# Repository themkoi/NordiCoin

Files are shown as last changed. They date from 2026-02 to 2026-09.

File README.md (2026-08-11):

<h1 align="center">
NordiCoin
</h1>

<p align="center">
Open source BLE tracker with up to 6 years of battery life on a single coin cell.
</p>

<p align="center">

</p>

<p align="center">
  
</p>

- It does not rely on a corporation BLE network to find it. Just you and your devices who track it. Dedicated android app and [watchy](https://github.com/Szybet/InkWatchy) support. The app alerts you once you are out of range
- Design focuses on easy self assembly by individuals
  - Wroom package used to avoid BGA soldering
  - Place for a second MCU in a different package, if the main one is not available. It also exposes all the pins for more features
- Buzzer, to find it easier and a button to stop buzzing
- Wanna use it as a remote for home automation? Sure, that's possible
- Built using the nrf52805
- Firmware written in rust
- Further potential to improve battery life

### Licence
Open Community License v1.1 + General Attribution v1

### Contact
Github issues, [Yatchy discord server](https://github.com/Szybet/Yatchy), [Quill OS matrix space](https://quill-os.org)

### Power consumption
It's a spectrum, the absolute best I got was 3.7uA



But this, at least with the current method is hard to connect to because it's 5s of advertisement delay, not 4s. With 4, it's around 4.5uA. Explore the `battery_life.ods` file to confirm

If someone really wanted to, it would be possible to sync time, advertise only on full minute, make the app do the same and this way it would advertise 15 times less. 10 years of battery life easily achievable. But connecting to it, at least with regular android phones would take long/impossible. That's why I decided the current setup is good enough

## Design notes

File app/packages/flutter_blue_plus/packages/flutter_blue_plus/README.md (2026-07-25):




<br>
<p align="center">
FlutterBlue
</p>
<br><br>

## Sponsor

<p align="left">
FlutterBlue
</p>

FlutterBluePlus is sponsored by [Jamcorder](https://www.jamcorder.com/). 

## License

FlutterBluePlus is licensed under the **[FlutterBluePlus License](./LICENSE.md)**.

* **Nonprofit use**: Free for personal use, nonprofits, and educational institutions. No license required.  
* **Commercial use**: For for-profit use, by for-profit organizations or individuals, a [Commercial License](https://jamcorder.myshopify.com/products/flutterblueplus-commercial-license) is required. This license grants *lifetime use*, covers all FlutterBluePlus packages, and includes *lifetime updates*.

---

**Note: this plugin is continuous work from [FlutterBlue](https://github.com/pauldemarco/flutter_blue).**

Migrating from [FlutterBlue](https://github.com/pauldemarco/flutter_blue)? See [Migration Guide](./MIGRATION.md)

## Contents

- [Introduction](#introduction)
- [Usage](#usage)
- [Getting Started](#getting-started)
- [Using Ble in App Background](#using-ble-in-app-background)
- [API Reference](#api-reference)
- [Debugging](#debugging)
- [Mocking](#mocking)
- [Common Problems](#common-problems)

## Introduction

FlutterBluePlus is a Bluetooth Low Energy plugin for [Flutter](https://flutter.dev). 

It supports BLE Central Role only (most common). 

If you need BLE Peripheral Role, you should check out [FlutterBlePeripheral](https://pub.dev/packages/flutter_ble_peripheral), or [bluetooth_low_energy](https://pub.dev/packages/bluetooth_low_energy).

## Tutorial

If you are new to Bluetooth, you should start by reading BLE tutorials.
* [Novel Bits BLE Tutorial](https://novelbits.io/bluetooth-low-energy-ble-complete-guide/)
* [All About Circuits BLE Tutorial](https://www.allaboutcircuits.com/technical-articles/exploring-the-basics-of-bluetooth-low-energy-a-beginners-guide-to-ble/)
* [Embetronicx BLE Tutorial](https://embetronicx.com/tutorials/tech_devices/bluetooth-low-energy-ble-introduction-part-1/)

## ❗ Bluetooth Classic is not supported ❗

 i.e. **Arduino HC-05 & HC-06,** speakers, headphones, mice, keyboards, gamepads, and more are **not** supported. These all use Bluetooth Classic.

 Also, iBeacons are **_not_** supported on iOS. Apple requires you to use CoreLocation.

## Cross-Platform Bluetooth Low Energy

FlutterBluePlus supports nearly every feature on all supported platforms: iOS, macOS, Android, Linux, Web.

## No Dependencies

FlutterBluePlus has zero dependencies besides Flutter, Android, iOS, and macOS themselves.

This makes FlutterBluePlus very stable, and easy to maintain.

## Windows Support

Use [flutter_blue_plus_winrt](https://pub.dev/packages/flutter_blue_plus_winrt) if you need Windows support.

It is maintained by [@chan150](https://github.com/chan150).

## ⭐ Stars ⭐

Please star this repo & on [pub.dev](https://pub.dev/packages/flutter_blue_plus). We all benefit from having a larger community.

## Discord 💬

 There is a community Discord server. ([Link](https://discord.gg/Yk5Efra))

## Example

FlutterBluePlus has a beautiful example app, useful to debug issues.

```
cd ./example
flutter run
```

<p align="center">
FlutterBlue
</p>

## Usage

### 🔥 Error Handling 🔥

Flutter Blue Plus takes error handling seriously. 

Every error returned by the native platform is checked and thrown as an exception where appropriate.

**Streams:** Streams returned by FlutterBluePlus never emit any errors and never close. There's no need to handle `onError` or `onDone` for  `stream.listen(...)`. The one exception is `FlutterBluePlus.scanResults`, which you should handle `onError`.

---

### Set Log Level

```dart
// if your terminal doesn't support color you'll see annoying logs like `\x1B[1;35m`
FlutterBluePlus.setLogLevel(LogLevel.verbose, color:false);

// optional
FlutterBluePlus.logs.listen((String s){
    // send logs anywhere you want
});
```

Setting `LogLevel.verbose` shows *all* data in and out.

⚫ = function name

🟣 = args to platform

🟡 = data from platform



### Bluetooth On & Off

**Note:** On iOS, a "*This app would like to use Bluetooth*" system dialogue appears on first call to any FlutterBluePlus method. 
 
```dart
// first, check if bluetooth is supported by your hardware
// Note: The platform is initialized on the first call to any FlutterBluePlus method.
if (await FlutterBluePlus.isSupported == false) {
    print("Bluetooth not supported by this device");
    return;
}

// handle bluetooth on & off
// note: for iOS the initial state is typically BluetoothAdapterState.unknown
// note: if you have permissions issues you will get stuck at BluetoothAdapterState.unauthorized
var subscription = FlutterBluePlus.adapterState.listen((BluetoothAdapterState state) {
    print(state);
    if (state == BluetoothAdapterState.on) {
        // usually start scanning, connecting, etc
    } else {
        // show an error to the user, etc
    }
});

// turn on bluetooth ourself if we can
// for iOS, the user controls bluetooth enable/disable
if (!kIsWeb && Platform.isAndroid) {
    await FlutterBluePlus.turnOn();
}

// cancel to prevent duplicate listeners
subscription.cancel();
```

### Scan for devices

If your device is not found, see [Common Problems](#common-problems).

**Note:** It is recommended to set scan filters to reduce main thread & platform channel usage.

```dart
// listen to scan results
// Note: `onScanResults` clears the results between scans. You should use
//  `scanResults` if you want the current scan results *or* the results from the previous scan.
var subscription = FlutterBluePlus.onScanResults.listen((results) {
        if (results.isNotEmpty) {
            ScanResult r = results.last; // the most recently found device
            print('${r.device.remoteId}: "${r.advertisementData.advName}" found!');
        }
    },
    onError: (e) => print(e),
);

// cleanup: cancel subscription when scanning stops
FlutterBluePlus.cancelWhenScanComplete(subscription);

// Wait for Bluetooth enabled & permission granted
// In your real app you should use `FlutterBluePlus.adapterState.listen` to handle all states
await FlutterBluePlus.adapterState.where((val) => val == BluetoothAdapterState.on).first;

// Start scanning w/ timeout
// Optional: use `stopScan()` as an alternative to timeout
await FlutterBluePlus.startScan(
  withServices:[Guid("180D")], // match any of the specified services
  withNames:["Bluno"], // *or* any of the specified names
  timeout: Duration(seconds:15));

// wait for scanning to stop
await FlutterBluePlus.isScanning.where((val) => val == false).first;
```

### Connect to a device

```dart
// listen for disconnection
var subscription = device.connectionState.listen((BluetoothConnectionState state) async {
    if (state == BluetoothConnectionState.disconnected) {
        // 1. typically, start a periodic timer that tries to 
        //    reconnect, or just call connect() again right now
        // 2. you must always re-discover services after disconnection!
        print("${device.disconnectReason?.code} ${device.disconnectReason?.description}");
    }
});

// cleanup: cancel subscription when disconnected
//   - [delayed] This option is only meant for `connectionState` subscriptions.  
//     When `true`, we cancel after a small delay. This ensures the `connectionState` 
//     listener receives the `disconnected` event.
//   - [next] if true, the the stream will be canceled only on the *next* disconnection,
//     not the current disconnection. This is useful if you setup your subscriptions
//     before you connect.
device.cancelWhenDisconnected(subscription, delayed:true, next:true);

// Connect to the device
await device.connect();

// Disconnect from device
await device.disconnect();

// cancel to prevent duplicate listeners
subscription.cancel();
```

### Auto Connect

Connects whenever your device is found.

```dart
// enable auto connect
//  - note: autoConnect is incompatible with mtu argument, so you must call requestMtu yourself
await device.connect(autoConnect:true, mtu:null)

// wait until connection
//  - when using autoConnect, connect() always returns immediately, so we must
//    explicity listen to `device.connectionState` to know when connection occurs 
await device.connectionState.where((val) => val == BluetoothConnectionState.connected).first;

// disable auto connect
await device.disconnect()
```

### Save Device

To save a device between app restarts, just write the `remoteId` to a file.

Now you can connect without needing to scan again, like so:

```dart
final String remoteId = await File('/remoteId.txt').readAsString();
var device = BluetoothDevice.fromId(remoteId);
// AutoConnect is convenient because it does not "time out"
// even if the device is not available / turned off.
await device.connect(autoConnect: true);

```

### MTU

On Android, we request an mtu of 512 by default during connection (see: `connect` function arguments).

On iOS & macOS, the mtu is negotiated automatically, typically 135 to 255.

```dart
final subscription = device.mtu.listen((int mtu) {
    // iOS: initial value is always 23, but iOS will quickly negotiate a higher value
    print("mtu $mtu");
});

// cleanup: cancel subscription when disconnected
device.cancelWhenDisconnected(subscription);

// You can also manually change the mtu yourself.
if (!kIsWeb && Platform.isAndroid) {
    await device.requestMtu(512);
}
```

### Discover services

```dart
// Note: You must call discoverServices after every re-connection!
List<BluetoothService> services = await device.discoverServices();
services.forEach((service) {
    // do something with service
});
```

### Read Characteristics

```dart
// Reads all characteristics
var characteristics = service.characteristics;
for(BluetoothCharacteristic c in characteristics) {
    if (c.properties.read) {
        List<int> value = await c.read();
        print(value);
    }
}
```

### Write Characteristic

```dart
// Writes to a characteristic
await c.write([0x12, 0x34]);
```

**allowLongWrite**: To write large characteristics (up to 512 bytes) regardless of mtu, use `allowLongWrite`:

```dart
/// allowLongWrite should be used with caution. 
///   1. it can only be used *with* response to avoid data loss
///   2. the peripheral device must support the 'long write' ble protocol.
///   3. Interrupted transfers can leave the characteristic in a partially written state
///   4. If the mtu is small, it is very very slow.
await c.write(data, allowLongWrite:true);
```

**splitWrite**: To write lots of data (unlimited), you can define the `splitWrite` function. 

```dart
import 'dart:math';
// split write should be used with caution.
//    1. due to splitting, `characteristic.read()` will return partial data.
//    2. it can only be used *with* response to avoid data loss
//    3. The characteristic must be designed to support split data
extension splitWrite on BluetoothCharacteristic {
  Future<void> splitWrite(List<int> value, {int timeout = 15}) async {
    int chunk = min(device.mtuNow - 3, 512); // 3 bytes BLE overhead, 512 bytes max
    for (int i = 0; i < value.length; i += chunk) {
      List<int> subvalue = value.sublist(i, min(i + chunk, value.length));
      await write(subvalue, withoutResponse:false, timeout: timeout);
    }
  }
}
```

### Subscribe to a characteristic

If `onValueReceived` is never called, see [Common Problems](#common-problems) in the README.

```dart
final subscription = characteristic.onValueReceived.listen((value) {
    // onValueReceived is updated:
    //   - anytime read() is called
    //   - anytime a notification arrives (if subscribed)
});

// cleanup: cancel subscription when disconnected
device.cancelWhenDisconnected(subscription);

// subscribe
// Note: If a characteristic supports both **notifications** and **indications**,
// it will default to **notifications**. This matches how CoreBluetooth works on iOS.
await characteristic.setNotifyValue(true);
```

### Last Value Stream

`lastValueStream` is an alternative to `onValueReceived`. It emits a value any time the characteristic changes, **including writes.**

It is very convenient for simple characteristics that support both WRITE and READ (and/or NOTIFY). **e.g.** a "light switch toggle" characteristic. 

```dart
final subscription = characteristic.lastValueStream.listen((value) {
    // lastValueStream` is updated:
    //   - anytime read() is called
    //   - anytime write() is called
    //   - anytime a notification arrives (if subscribed)
    //   - also when first listened to, it re-emits the last value for convenience.
});

// cleanup: cancel subscription when disconnected
device.cancelWhenDisconnected(subscription);

// enable notifications
await characteristic.setNotifyValue(true);
```

### Read and write descriptors

```dart
// Reads all descriptors
var descriptors = characteristic.descriptors;
for(BluetoothDescriptor d in descriptors) {
    List<int> value = await d.read();
    print(value);
}

// Writes to a descriptor
await d.write([0x12, 0x34])
```

### Services Changed Characteristic

FlutterBluePlus automatically listens to the Services Changed Characteristic (0x2A05)

In FlutterBluePlus, we call it `onServicesReset` because you must re-discover services.

```dart
// - uses the GAP Services Changed characteristic (0x2A05)
// - you must call discoverServices() again
device.onServicesReset.listen(() async {
    print("Services Reset");
    await device.discoverServices();
});
```

### Get Connected Devices

Get devices currently connected to your app.

```dart
List<BluetoothDevice> devs = FlutterBluePlus.connectedDevices;
for (var d in devs) {
    print(d);
}
```

### Get System Devices

Get devices connected to the system by *any* app.

**Note:** before you can communicate, you must connect *your app* to these devices 

```dart
// `withServices` required on iOS, ignored on android
List<Guid> withServices = [Guid("180F")]; // e.g. Battery Service
List<BluetoothDevice> devs = await FlutterBluePlus.systemDevices(withServices);
for (var d in devs) {
    await d.connect(); // Must connect *our* app to the device
    await d.discoverServices();
}
```

### Create Bond (Android Only)

**Note:** calling this is usually not necessary!! The platform will do it automatically. 

However, you can force the popup to show sooner.

```dart
final bsSubscription = device.bondState.listen((value) {
    print("$value prev:{$device.prevBondState}");
});

// cleanup: cancel subscription when disconnected
device.cancelWhenDisconnected(bsSubscription);

// Force the bonding popup to show now (Android Only) 
await device.createBond();

// remove bond
await device.removeBond();
```

### Events API

Access streams from all devices simultaneously.

There are streams for:
* events.onConnectionStateChanged
* events.onMtuChanged
* events.onReadRssi
* events.onServicesReset
* events.onDiscoveredServices
* events.onCharacteristicReceived
* events.onCharacteristicWritten
* events.onDescriptorRead
* events.onDescriptorWritten
* events.onNameChanged (iOS Only)
* events.onBondStateChanged (Android Only)

```dart
// listen to *any device* connection state changes 
FlutterBluePlus.events.onConnectionStateChanged.listen((event)) {
    print('${event.device} ${event.connectionState}');
}
```

### Multi Device Performance

We recommend setting per-device queueing. 

```dart
// note: call this function before starting any other FBP work
FlutterBluePlus.setOperationQueueMode(OperationQueueMode.perDevice);
```

This allows BLE operations on different devices to run at the same time, increasing multi-device performance.

## Mocking

To mock `FlutterBluePlus` for development, refer to the [Mocking Guide](MOCKING.md).

## Getting Started

### Add the `flutter_blue_plus` plugin

We recommend that you pin to a specific version of the `flutter_blue_plus` plugin for maximum stability and to avoid small breaking changes.

```shell
flutter pub add flutter_blue_plus:x.y.z
```

`flutter_blue_plus` is a [federated plugin](https://docs.flutter.dev/packages-and-plugins/developing-packages#federated-plugins) with endorsed platform implementations therefore you only need to add the "app-facing package" to your `pubspec.yaml` file.

### Change the minSdkVersion for Android

flutter_blue_plus is compatible only from version 21 of Android SDK so you should change this in **android/app/build.gradle**:

```dart
android {
  defaultConfig {
     minSdkVersion: 21
```

### Add permissions for Android (No Location)

In the **android/app/src/main/AndroidManifest.xml** add:

```xml
<!-- Tell Google Play Store that your app uses Bluetooth LE
     Set android:required="true" if bluetooth is necessary -->
<uses-feature android:name="android.hardware.bluetooth_le" android:required="false" />

<!-- New Bluetooth permissions in Android 12
https://developer.android.com/about/versions/12/features/bluetooth-permissions -->
<uses-permission android:name="android.permission.BLUETOOTH_SCAN" android:usesPermissionFlags="neverForLocation" />
<uses-permission android:name="android.permission.BLUETOOTH_CONNECT" />

<!-- legacy for Android 11 or lower -->
<uses-permission android:name="android.permission.BLUETOOTH" android:maxSdkVersion="30" />
<uses-permission android:name="android.permission.BLUETOOTH_ADMIN" android:maxSdkVersion="30" />
<uses-permission android:name="android.permission.ACCESS_FINE_LOCATION" android:maxSdkVersion="30"/>

<!-- legacy for Android 9 or lower -->
<uses-permission android:name="android.permission.ACCESS_COARSE_LOCATION" android:maxSdkVersion="28" />
```

### Add permissions for Android (With Fine Location)

If you want to use Bluetooth to determine location, or support iBeacons.

In the **android/app/src/main/AndroidManifest.xml** add:

```xml
<!-- Tell Google Play Store that your app uses Bluetooth LE
     Set android:required="true" if bluetooth is necessary -->
<uses-feature android:name="android.hardware.bluetooth_le" android:required="false" />

<!-- New Bluetooth permissions in Android 12
https://developer.android.com/about/versions/12/features/bluetooth-permissions -->
<uses-permission android:name="android.permission.BLUETOOTH_SCAN"/>
<uses-permission android:name="android.permission.BLUETOOTH_CONNECT" />
<uses-permission android:name="android.permission.ACCESS_FINE_LOCATION" />

<!-- legacy for Android 11 or lower -->
<uses-permission android:name="android.permission.BLUETOOTH" android:maxSdkVersion="30" />
<uses-permission android:name="android.permission.BLUETOOTH_ADMIN" android:maxSdkVersion="30" />

<!-- legacy for Android 9 or lower -->
<uses-permission android:name="android.permission.ACCESS_COARSE_LOCATION" android:maxSdkVersion="28" />
```

And set **androidUsesFineLocation** when scanning:
```dart
// Start scanning
flutterBlue.startScan(timeout: Duration(seconds: 4), androidUsesFineLocation: true);
```

### Android Proguard

Add the following line in your `project/android/app/proguard-rules.pro` file:

```
-keep class com.lib.flutter_blue_plus.* { *; }
```

to avoid seeing the following kind errors in your `release` builds:

```
PlatformException(startScan, Field androidScanMode_ for m0.e0 not found. Known fields are
 [private int m0.e0.q, private b3.b0$i m0.e0.r, private boolean m0.e0.s, private static final m0.e0 m0.e0.t,
 private static volatile b3.a1 m0.e0.u], java.lang.RuntimeException: Field androidScanMode_ for m0.e0 not found
```

### Add permissions for iOS

In the **ios/Runner/Info.plist** let’s add:

```dart
<dict>
...
    <key>NSBluetoothAlwaysUsageDescription</key>
    <string>This app needs Bluetooth to function</string>
...
</dict>
```

For location permissions on iOS see more at: [https://developer.apple.com/documentation/corelocation/requesting_authorization_for_location_services](https://developer.apple.com/documentation/corelocation/requesting_authorization_for_location_services)

### Add permissions for macOS 

Make sure you have granted access to the Bluetooth hardware:

`Xcode -> Runners -> Targets -> Runner-> Signing & Capabilities -> App Sandbox -> Hardware -> Enable Bluetooth`



## Using Ble in App Background

**This is an advanced use case**. FlutterBluePlus does not support everything. You may have to fork it. PRs are welcome.

### iOS

Documentation: https://developer.apple.com/library/archive/documentation/NetworkingInternetWeb/Conceptual/CoreBluetooth_concepts/CoreBluetoothBackgroundProcessingForIOSApps/Perform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

Add the following to your `Info.plist`

```
<key>UIBackgroundModes</key>
<array>
    <string>bluetooth-central</string>
</array>
```

When this key-value pair is included in the app’s Info.plist file, the system wakes up your app to process ble `read`, `write`, and `subscription` events.

To wake up your app even after it is killed by the OS, set the `restoreState` option to true **before** starting any FBP work**:

```
FlutterBluePlus.setOptions(restoreState: true);
```

**Note**: Upon being woken up, an app has around 10 seconds to complete a task. Apps that spend too much time executing in the background can be throttled back by the system or killed.

### Android

You can try using https://pub.dev/packages/flutter_foreground_task or possibly https://pub.dev/packages/workmanager

## API Reference

Note: When functionality is unsupported on a platform, sensible defaults are returned instead of an error.

* 🌀 = Stream
* ⚡ = Synchronous
* 🔥 = Can fail

| | Android | iOS/macOS | Linux | Web | Description |
|---|---|---|---|-----|---|
| setLogLevel | ✔️ | ✔️ | ✔️ | ❌ | Configure plugin log level |
| setOptions | ✔️ | ✔️ | ❌ | ❌ | Set configurable bluetooth options |
| setOperationQueueMode ⚡| ✔️ | ✔️ | ✔️ | ✔️  | Configure whether BLE operations queue globally or per-device |
| isSupported | ✔️ | ✔️ | ✔️ | ✔️  | Checks whether the device supports Bluetooth |
| turnOn 🔥| ✔️ | ❌ | ✔️ | ❌ | Turns on the bluetooth adapter |
| turnOff 🔥| ✔️ | ❌ | ✔️ | ❌ | Turns off the bluetooth adapter |
| adapterStateNow ⚡| ✔️ | ✔️ | ✔️ | ❌ | Current state of the bluetooth adapter |
| adapterState 🌀| ✔️ | ✔️ | ✔️ | ❌ | Stream of on & off states of the bluetooth adapter |
| startScan 🔥| ✔️ | ✔️ | ✔️ | ✔️  | Starts a scan for Ble devices |
| stopScan 🔥| ✔️ | ✔️ | ✔️ | ❌ | Stop an existing scan for Ble devices |
| onScanResults 🌀🔥| ✔️ | ✔️ | ✔️ | ✔️  | Stream of live scan results |
| scanResults 🌀🔥| ✔️ | ✔️ | ✔️ | ✔️  | Stream of live scan results or previous results |
| lastScanResults ⚡| ✔️ | ✔️ | ✔️ | ✔️  | The most recent scan results |
| isScanning 🌀| ✔️ | ✔️ | ✔️ | ✔️  | Stream of current scanning state |
| isScanningNow ⚡| ✔️ | ✔️ | ✔️ | ✔️  | Is a scan currently running? |
| connectedDevices ⚡| ✔️ | ✔️ | ✔️ | ✔️  | List of devices connected to *your app* |
| systemDevices 🔥| ✔️ | ✔️ | ✔️ | ❌ | List of devices connected to the system, even by other apps |
| getPhySupport | ✔️ | ❌ | ❌ | ❌ | Get supported bluetooth phy codings |

### FlutterBluePlus Events API

| | Android | iOS/macOS | Linux | Web | Description |
|---|---|---|---|-----|---|
| onConnectionStateChanged 🌀| ✔️ | ✔️ | ✔️ | ✔️  | Stream of connection changes of *all devices* |
| onMtuChanged 🌀| ✔️ | ✔️ | ❌ | ❌ | Stream of mtu changes of *all devices* |
| onReadRssi 🌀| ✔️ | ✔️ | ✔️ | ❌ | Stream of rssi reads of *all devices* |
| onServicesReset 🌀| ✔️ | ✔️ | ✔️ | ❌ | Stream of services resets of *all devices* |
| onDiscoveredServices 🌀| ✔️ | ✔️ | ✔️ | ✔️  | Stream of services discovered of *all devices* |
| onCharacteristicReceived 🌀| ✔️ | ✔️ | ✔️ | ✔️  | Stream of characteristic value reads of *all devices*  |
| onCharacteristicWritten  🌀| ✔️ | ✔️ | ✔️ | ✔️  | Stream of characteristic value writes of *all devices* |
| onDescriptorRead 🌀| ✔️ | ✔️ | ✔️ | ✔️  | Stream of descriptor value reads of *all devices* |
| onDescriptorWritten 🌀| ✔️ | ✔️ | ✔️ | ✔️  | Stream of descriptor value writes of *all devices* |
| onBondStateChanged 🌀| ✔️ | ❌ | ✔️ | ❌ | Stream of bond state changes of *all devices* |
| onNameChanged 🌀| ❌ | ✔️ | ✔️ | ❌ | Stream of name changes of *all devices* |

### BluetoothDevice API

| | Android | iOS/macOS | Linux | Web | Description |
|---|---|---|---|-----|---|
| platformName ⚡| ✔️ | ✔️ | ✔️ | ✔️  | The platform preferred name of the device |
| advName ⚡| ✔️ | ✔️ | ❌ | ❌ | The advertised name of the device found during scanning |
| connect 🔥| ✔️ | ✔️ | ✔️ | ✔️  | Establishes a connection to the device |
| disconnect 🔥| ✔️ | ✔️ | ✔️ | ✔️  | Cancels an active or pending connection to the device |
| isConnected ⚡| ✔️ | ✔️ | ✔️ | ✔️  | Is this device currently connected to *your app*? |
| isDisconnected ⚡| ✔️ | ✔️ | ✔️ | ✔️  | Is this device currently disconnected from *your app*? |
| connectionState 🌀| ✔️ | ✔️ | ✔️ | ✔️  | Stream of connection changes for the Bluetooth Device |
| discoverServices 🔥| ✔️ | ✔️ | ✔️ | ✔️  | Discover services |
| servicesList ⚡| ✔️ | ✔️ | ✔️ | ✔️  | The current list of available services |
| onServicesReset 🌀| ✔️ | ✔️ | ✔️ | ❌ | The services changed & must be rediscovered |
| mtu 🌀| ✔️ | ✔️ | ❌ | ❌ | Stream of current mtu value + changes |
| mtuNow ⚡| ✔️ | ✔️ | ❌ | ❌ | The current mtu value |
| readRssi 🔥| ✔️ | ✔️ | ✔️ | ❌ | Read RSSI from a connected device |
| requestMtu 🔥| ✔️ | ❌ | ❌ | ❌ | Request to change the MTU for the device |
| requestConnectionPriority 🔥| ✔️ | ❌ | ❌ | ❌ | Request to update a high priority, low latency connection  |
| bondState 🌀| ✔️ | ❌ | ✔️ | ❌ | Stream of device bond state. Can be useful on Android |
| createBond 🔥| ✔️ | ❌ | ✔️ | ❌ | Force a system pairing dialogue to show, if needed |
| removeBond | ✔️ | ❌ | ✔️ | ❌ | Remove Bluetooth Bond of device |
| setPreferredPhy | ✔️ | ❌ | ❌ | ❌ | Set preferred RX and TX phy for connection and phy options |
| clearGattCache | ✔️ | ❌ | ❌ | ❌ | Clear android cache of service discovery results |

### BluetoothCharacteristic API

| | Android | iOS/macOS | Linux | Web | Description |
|---|---|---|---|-----|---|
| uuid ⚡| ✔️ | ✔️ | ✔️ | ✔️  | The uuid of characteristic |
| read 🔥| ✔️ | ✔️ | ✔️ | ✔️  | Retrieves the value of the characteristic |
| write 🔥| ✔️ | ✔️ | ✔️ | ✔️  | Writes the value of the characteristic |
| setNotifyValue  🔥| ✔️ | ✔️ | ✔️ | ✔️  | Sets notifications or indications on the characteristic |
| isNotifying ⚡| ✔️ | ✔️ | ✔️ | ✔️  | Are notifications or indications currently enabled |
| onValueReceived 🌀| ✔️ | ✔️ | ✔️ | ✔️  | Stream of characteristic value updates received from the device |
| lastValue ⚡| ✔️ | ✔️ | ✔️ | ✔️  | The most recent value of the characteristic |
| lastValueStream 🌀| ✔️ | ✔️ | ✔️ | ✔️  | Stream of onValueReceived + writes |

### BluetoothDescriptor API

| | Android | iOS/macOS | Linux | Web | Description |
|---|---|---|---|-----|---|
| uuid ⚡| ✔️ | ✔️ | ✔️ | ✔️  | The uuid of descriptor |
| read 🔥| ✔️ | ✔️ | ✔️ | ✔️  | Retrieves the value of the descriptor |
| write 🔥| ✔️ | ✔️ | ✔️ | ✔️  | Writes the value of the descriptor |
| onValueReceived 🌀| ✔️ | ✔️ | ✔️ | ✔️  | Stream of descriptor value reads & writes |
| lastValue ⚡| ✔️ | ✔️ | ✔️ | ✔️  | The most recent value of the descriptor |
| lastValueStream 🌀| ✔️ | ✔️ | ✔️ | ✔️  | Stream of onValueReceived + writes |

## Debugging

The easiest way to debug issues in FlutterBluePlus is to make your own local copy.

```
cd /user/downloads
git clone https://github.com/chipweinberger/flutter_blue_plus.git
```

then in `pubspec.yaml` add the repo by path:

```
  flutter_blue_plus:
    path: /user/downloads/flutter_blue_plus
```

Now you can edit the FlutterBluePlus code yourself.

## Common Problems

Many common problems are easily solved.

Adapter:
- [bluetooth must be turned on](#bluetooth-must-be-turned-on)
- [adapterState is not 'on' but my Bluetooth is on](#adapterstate-is-not-on-but-my-bluetooth-is-on)
- [adapterState is called multiple times](#adapterstate-is-called-multiple-times)

Scanning:
- [Scanning does not find my device](#scanning-does-not-find-my-device)
- [Scanned device never goes away](#scanned-device-never-goes-away)
- [iBeacons not showing](#ibeacons-not-showing)

Connecting:
- [Connection fails](#connection-fails)
- [connectionState is called multiple times](#connectionstate-is-called-multiple-times)
- [remoteId is different on Android vs iOS](#the-remoteid-is-different-on-android-versus-ios--macos)
- [iOS: "[Error] The connection has timed out unexpectedly."](#ios-error-the-connection-has-timed-out-unexpectedly)

Reading & Writing:
- [List of Bluetooth GATT Errors](#list-of-bluetooth-gatt-errors)
- [Characteristic write fails](#characteristic-write-fails)
- [Characteristic read fails](#characteristic-read-fails)

Subscriptions:
- [onValueReceived is never called (or lastValueStream)](#onvaluereceived-is-never-called-or-lastvaluestream)
- [onValueReceived data is split up (or lastValueStream)](#onvaluereceived-data-is-split-up-or-lastvaluestream)
- [onValueReceived is called with duplicate data (or lastValueStream)](#onvaluereceived-is-called-with-duplicate-data-or-lastvaluestream)

Android Errors:
- [ANDROID_SPECIFIC_ERROR](#android_specific_error)
- [android pairing popup appears twice](#android-pairing-popup-appears-twice)

Flutter Errors:
- [MissingPluginException(No implementation found for method XXXX ...)](#missingpluginexceptionno-implementation-found-for-method-xxxx-)

---

### "bluetooth must be turned on"

You need to wait for the bluetooth adapter to fully turn on. 

`await FlutterBluePlus.adapterState.where((state) => state == BluetoothAdapterState.on).first;`

You can also use `FlutterBluePlus.adapterState.listen(...)`. See [Usage](#usage).

---

### adapterState is not 'on' but my Bluetooth is on

**For iOS:**

`adapterState` always starts as `unknown`. You need to wait longer for the service to initialize. As simple as:

```
if (await FlutterBluePlus.adapterState.first == BluetoothAdapterState.unknown) {
    await Future.delayed(const Duration(seconds: 1));
}
```

If `adapterState` is `unavailable`, you must add access to Bluetooth Hardware in the app's Xcode settings. See [Getting Started](#getting-started).

**For Android:**

Check that your device supports Bluetooth & has permissions.

---

### adapterState is called multiple times

You are forgetting to cancel the original `FlutterBluePlus.adapterState.listen` resulting in multiple listeners.

```dart
// tip: using ??= makes it easy to only make new listener when currently null
final subscription ??= FlutterBluePlus.adapterState.listen((value) {
    // ...
});

// also, make sure you cancel the subscription when done!
subscription.cancel()
```

---

### Scanning does not find my device

**1. you're using an emulator**

Use a physical device.

**2. try using another ble scanner app**

* **iOS**: [nRF Connect](https://apps.apple.com/us/app/nrf-connect-for-mobile/id1054362403)
* **Android**: [BLE Scanner](https://play.google.com/store/apps/details?id=com.macdom.ble.blescanner)

Install a BLE scanner app on your phone. Can it find your device?

**3. your device uses bluetooth classic, not BLE.**

Headphones, speakers, keyboards, mice, gamepads, & printers all use Bluetooth Classic. 

These devices may be found in System Settings, but they cannot be connected to by FlutterBluePlus. FlutterBluePlus only supports Bluetooth Low Energy.

**4. your device stopped advertising.**

- you might need to reboot your device
- you might need to put your device in "discovery mode"
- your phone may have already connected automatically
- another app may have already connected to your device
- another phone may have already connected to your device

Try looking through system devices:

```dart
// search system devices. i.e. any device connected to by *any* app
List<BluetoothDevice> system = await FlutterBluePlus.systemDevices;
for (var d in system) {
    print('${r.device.platformName} already connected to! ${r.device.remoteId}');
    if (d.platformName == "myBleDevice") {
         await r.connect(); // must connect our app
    }
}
```

**5. your scan filters are wrong.**

- try removing all scan filters
- for `withServices` to work, your device must actively advertise the serviceUUIDs it supports

**6. Android: you're calling startScan too often**

On Adroid you can only call `startScan` 5 times per 30 second period. This is a platform restriction.

**7. Android: make sure location services are enabled**

Android requires location services to allow bluetooth scanning.

---

### Scanned device never goes away

This is expected.

You must set the `removeIfGone` scan option if you want the device to go away when no longer available.

---

### iBeacons Not Showing

**iOS:**

iOS does not support iBeacons using CoreBluetooth. You must find a plugin meant for CoreLocation.

**Android:**

1. you need to enable location permissions, see [Getting Started](#getting-started)
2. you must pass `androidUsesFineLocation:true` to the `startScan` method.

---

### Connection fails

**1. Your ble device may be low battery**

Bluetooth can become erratic when your peripheral device is low on battery.

**2. Your ble device may have refused the connection or have a bug**

Connection is a two-way process. Your ble device may be misconfigured.

**3. You may be on the edge of the Bluetooth range.**

The signal is too weak, or there are a lot of devices causing radio interference.

**4. Some phones have an issue connecting while scanning.**

The Huawei P8 Lite is one of the reported phones to have this issue. Try stopping your scanner before connecting.

**5. Try restarting your phone**

Bluetooth is a complicated system service, and can enter a bad state.

---

### connectionState is called multiple times

You are forgetting to cancel the original `device.connectionState.listen` resulting in multiple listeners.

```dart
// tip: using ??= makes it easy to only make new listener when currently null
final subscription ??= FlutterBluePlus.device.connectionState.listen((value) {
    // ...
});

// also, make sure you cancel the subscription when done!
subscription.cancel()
```

---

### The remoteId is different on Android versus iOS & macOS

This is expected. There is no way to avoid it.

For privacy, iOS & macOS use a randomly generated uuid. This uuid will periodically change.

e.g. `6920a902-ba0e-4a13-a35f-6bc91161c517`

Android uses the mac address of the bluetooth device. It never changes.

e.g. `05:A4:22:31:F7:ED`

---

### iOS: "[Error] The connection has timed out unexpectedly."

You can google this error. It is a common iOS ble error code.

It means your device stopped working. FlutterBluePlus cannot fix it.

---

### List of Bluetooth GATT Errors

These GATT error codes are part of the BLE Specification. 

**These are *responses* from your ble device because you are sending an invalid request.**

FlutterBluePlus cannot fix these errors. You are doing something wrong & your device is responding with an error.

**GATT errors as they appear on iOS**:
```
apple-code: 1  | The handle is invalid.
apple-code: 2  | Reading is not permitted.
apple-code: 3  | Writing is not permitted.
apple-code: 4  | The command is invalid.
apple-code: 6  | The request is not supported.
apple-code: 7  | The offset is invalid.
apple-code: 8  | Authorization is insufficient.
apple-code: 9  | The prepare queue is full.
apple-code: 10 | The attribute could not be found.
apple-code: 11 | The attribute is not long.
apple-code: 12 | The encryption key size is insufficient.
apple-code: 13 | The value's length is invalid.
apple-code: 14 | Unlikely error.
apple-code: 15 | Encryption is insufficient.
apple-code: 16 | The group type is unsupported.
apple-code: 17 | Resources are insufficient.
apple-code: 18 | Unknown ATT error.
```

**GATT errors as they appear on Android**:
```
android-code: 1  | GATT_INVALID_HANDLE
android-code: 2  | GATT_READ_NOT_PERMITTED
android-code: 3  | GATT_WRITE_NOT_PERMITTED
android-code: 4  | GATT_INVALID_PDU
android-code: 5  | GATT_INSUFFICIENT_AUTHENTICATION
android-code: 6  | GATT_REQUEST_NOT_SUPPORTED
android-code: 7  | GATT_INVALID_OFFSET
android-code: 8  | GATT_INSUFFICIENT_AUTHORIZATION
android-code: 9  | GATT_PREPARE_QUEUE_FULL
android-code: 10 | GATT_ATTR_NOT_FOUND
android-code: 11 | GATT_ATTR_NOT_LONG
android-code: 12 | GATT_INSUFFICIENT_KEY_SIZE
android-code: 13 | GATT_INVALID_ATTRIBUTE_LENGTH
android-code: 14 | GATT_UNLIKELY
android-code: 15 | GATT_INSUFFICIENT_ENCRYPTION
android-code: 16 | GATT_UNSUPPORTED_GROUP
android-code: 17 | GATT_INSUFFICIENT_RESOURCES
```

**Descriptions**:
```
1   | Invalid Handle                 | The attribute handle given was not valid on this server.
2   | Read Not Permitted             | The attribute cannot be read.
3   | Write Not Permitted            | The attribute cannot be written.
4   | Invalid PDU                    | The attribute PDU was invalid.
5   | Insufficient Authentication    | The attribute requires authentication before it can be read or written.
6   | Request Not Supported          | Attribute server does not support the request received from the client.
7   | Invalid Offset                 | Offset specified was past the end of the attribute.
8   | Insufficient Authorization     | The attribute requires an authorization before it can be read or written.
9   | Prepare Queue Full             | Too many prepare writes have been queued.
10  | Attribute Not Found            | No attribute found within the given attribute handle range.
11  | Attribute Not Long             | The attribute cannot be read or written using the Read Blob or Write Blob requests.
12  | Insufficient Key Size          | The Encryption Key Size used for encrypting this link is insufficient.
13  | Invalid Attribute Value Length | The attribute value length is invalid for the operation.
14  | Unlikely Error                 | The request has encountered an unlikely error and cannot be completed.
15  | Insufficient Encryption        | The attribute requires encryption before it can be read or written.
16  | Unsupported Group Type         | The attribute type is not a supported grouping as defined by a higher layer.
17  | Insufficient Resources         | Insufficient Resources to complete the request.
```

---

### characteristic write fails

First, check the [List of Bluetooth GATT Errors](#list-of-bluetooth-gatt-errors) for your error.

**1. your bluetooth device turned off, or is out of range**

If your device turns off or crashes during a write, it will cause a failure.

**2. Your Bluetooth device has bugs**

Maybe your device crashed, or is not sending a response due to software bugs.

**3. there is radio interference**

Bluetooth is wireless and will not always work.

---

### Characteristic read fails

First, check the [List of Bluetooth GATT Errors](#list-of-bluetooth-gatt-errors) for your error.

**1. your bluetooth device turned off, or is out of range**

If your device turns off or crashes during a read, it will cause a failure.

**2. Your Bluetooth device has bugs**

Maybe your device crashed, or is not sending a response due to software bugs.

**3. there is radio interference**

Bluetooth is wireless and will not always work.

---

### onValueReceived is never called (or lastValueStream)

**1. you are not calling the right function**

`lastValueStream` will receive data for `chr.read()` & `chr.write()` & `chr.setNotifyValue(true)` 

`onValueReceived` will receive data for `chr.read()` & `chr.setNotifyValue(true)` 

**2. your device has nothing to send**

If you are using `chr.setNotifyValue(true)`, your _device_ chooses when to send data.

Try interacting with your device to get it to send new data.

**3. your device has bugs**

Try rebooting your ble device. 

Some ble devices have buggy software and stop sending data

---

### onValueReceived data is split up (or lastValueStream)

Verify that the mtu is large enough to hold your message.

```dart
device.mtu
```

If it still happens, it is a problem with your peripheral device.

---

### onValueReceived is called with duplicate data (or lastValueStream)

You are probably forgetting to cancel the original `chr.onValueReceived.listen` resulting in multiple listens.

The easiest solution is to use `device.cancelWhenDisconnected(subscription)` to cancel device subscriptions.

```dart
final subscription = chr.onValueReceived.listen((value) {
    // ...
});

// make sure you have this line!
device.cancelWhenDisconnected(subscription);

await characteristic.setNotifyValue(true);
```

---

### ANDROID_SPECIFIC_ERROR

There is no 100% solution.  

FBP already has mitigations for this error, but Android will still fail with this code randomly. 

The recommended solution is to `catch` the error, and retry.

---

### android pairing popup appears twice

This is a bug in android itself.

You can call `createBond()` yourself just after connecting and this will resolve the issue.

---

### MissingPluginException(No implementation found for method XXXX ...)

If you just added flutter_blue_plus to your pubspec.yaml, a hot reload / hot restart is not enough.

You need to fully stop your app and run again so that the native plugins are loaded.

Also try `flutter clean`.

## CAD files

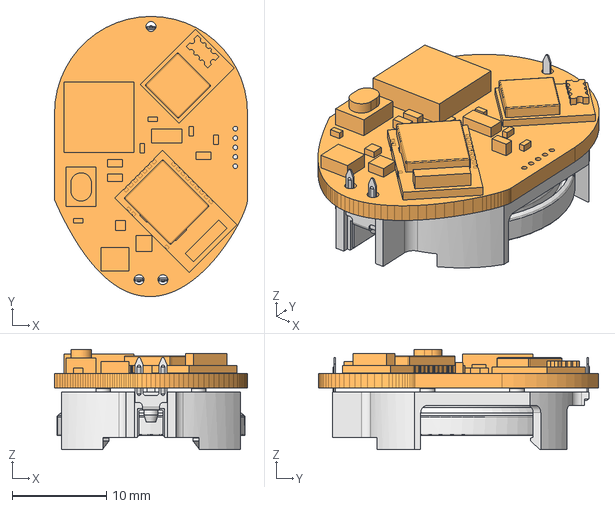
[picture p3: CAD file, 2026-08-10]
3D/PCB & Cr2032 socket.step
20.5 x 29.8 x 10.7 mm

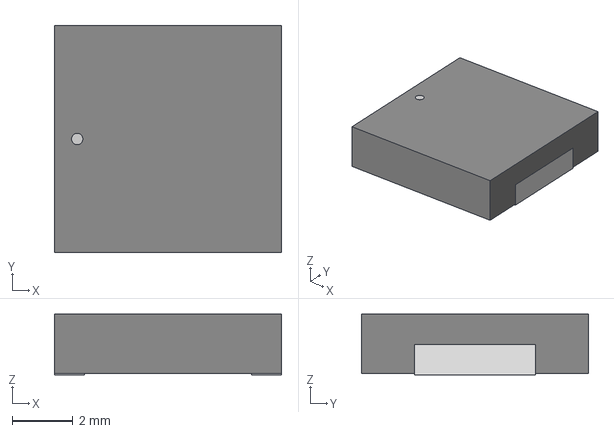
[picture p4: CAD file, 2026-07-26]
hardware/components/3D/AST0760_MAL.step
7.49 x 7.49 x 2.01 mm

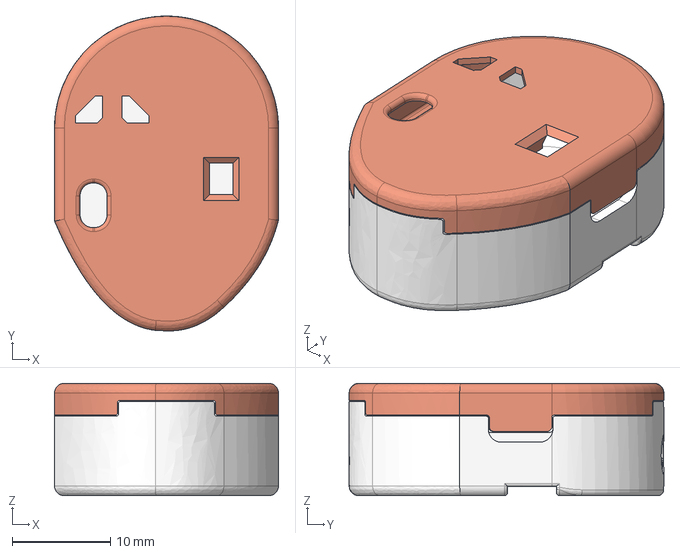
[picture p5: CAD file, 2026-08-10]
3D/Case for CR2032.step
22.8 x 32.1 x 11.5 mm

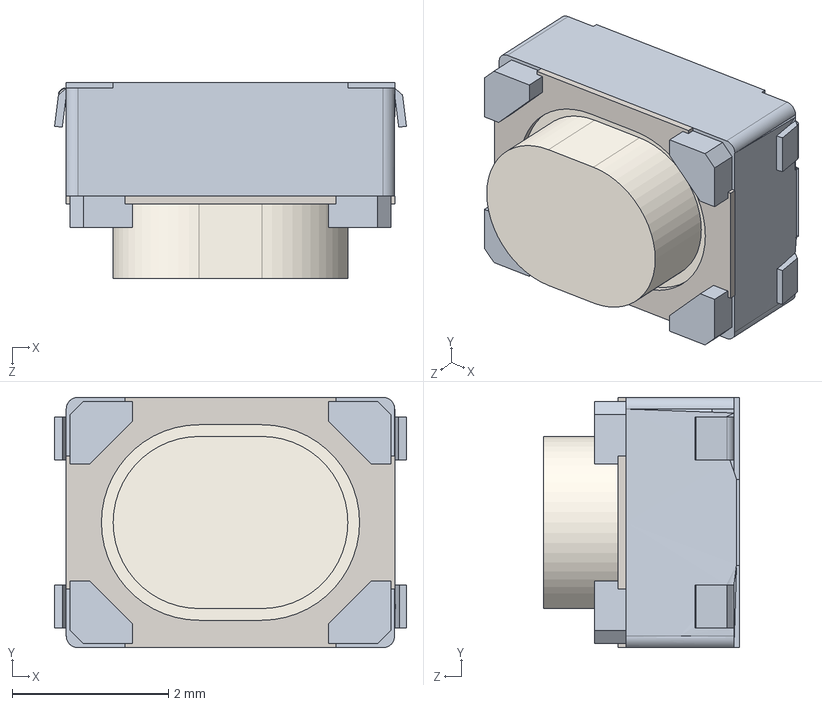
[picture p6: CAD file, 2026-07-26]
hardware/components/3D/PTS815SJM250SMTR_LFS.stp
4.50 x 3.20 x 2.50 mm
PTS815SJM250SMTRLFS_PART1
PTS815SJM250SMTRLFS_PART2
PTS815SJM250SMTRLFS_PART3_2
PTS815SJM250SMTRLFS_PART3
PTS815SJM250SMTRLFS_PART3_1
PTS815SJM250SMTRLFS_PART3_4
PTS815SJM250SMTRLFS_PART3_3

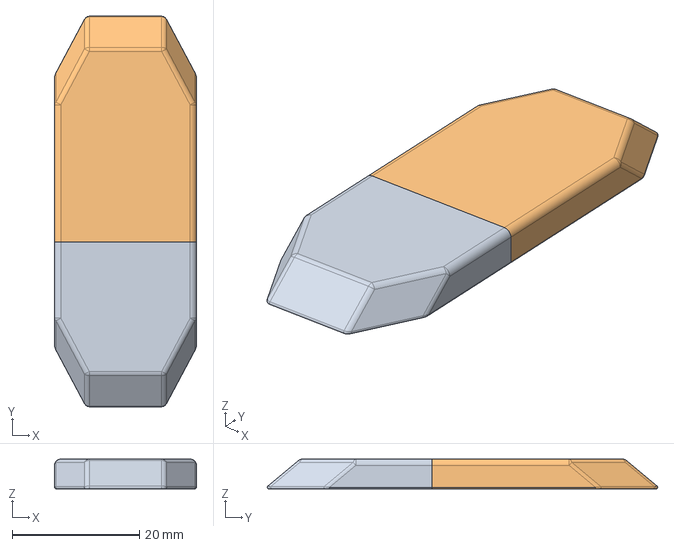
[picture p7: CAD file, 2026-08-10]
3D/Flat case.step
22.3 x 61.4 x 4.69 mm

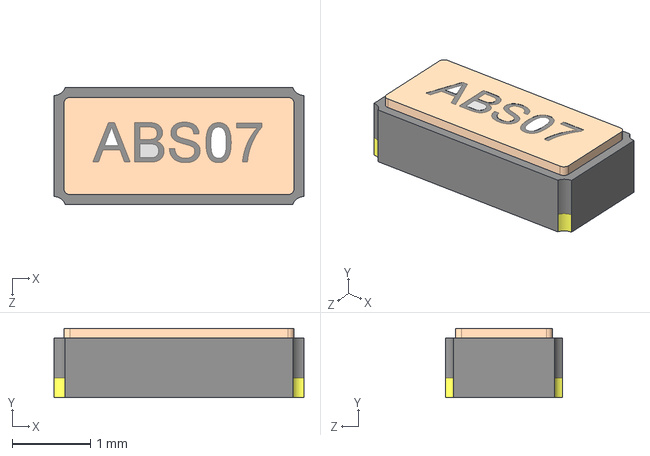
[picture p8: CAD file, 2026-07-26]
hardware/components/3D/ABS07-32.768KHZ-T--3DModel-STEP-400430.STEP
3.20 x 0.889 x 1.50 mm

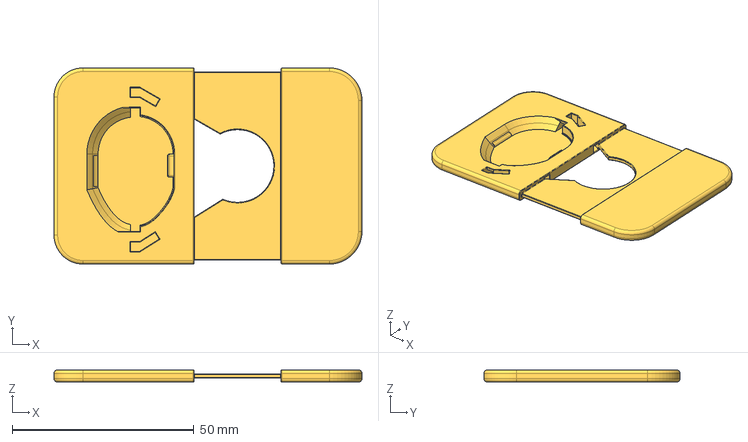
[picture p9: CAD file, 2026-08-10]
3D/Card case.step
84.8 x 54.0 x 3.39 mm

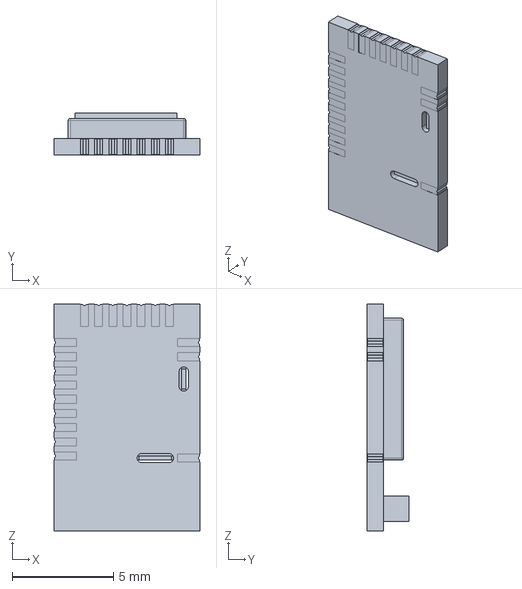
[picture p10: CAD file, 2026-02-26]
hardware/components/3D/MDBT42T.stp
7.20 x 2.05 x 11.2 mm

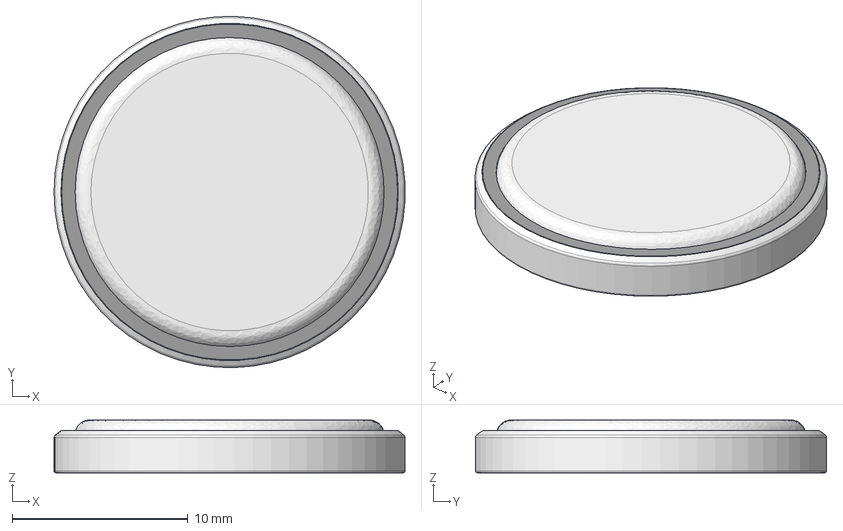
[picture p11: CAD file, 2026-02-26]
hardware/components/3D/CR2032.step
20.0 x 20.0 x 3.01 mm
conn_pos
conn_neg
insulator
ShapeString
ShapeString001
ShapeString002

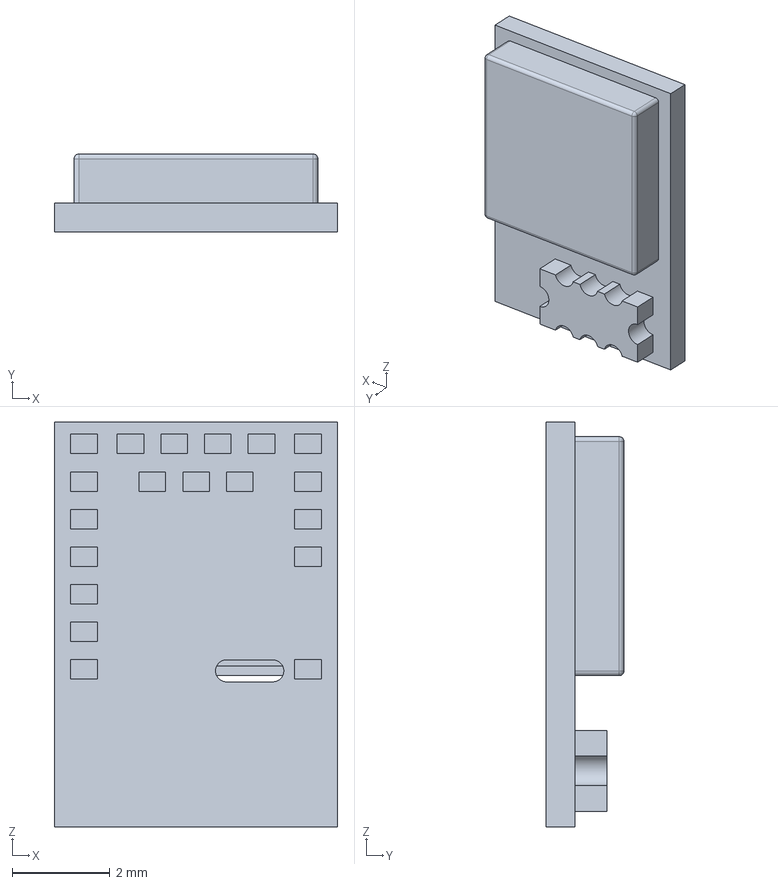
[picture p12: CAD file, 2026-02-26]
hardware/components/3D/MDBT42TV_20191030.stp
5.80 x 1.60 x 8.30 mm

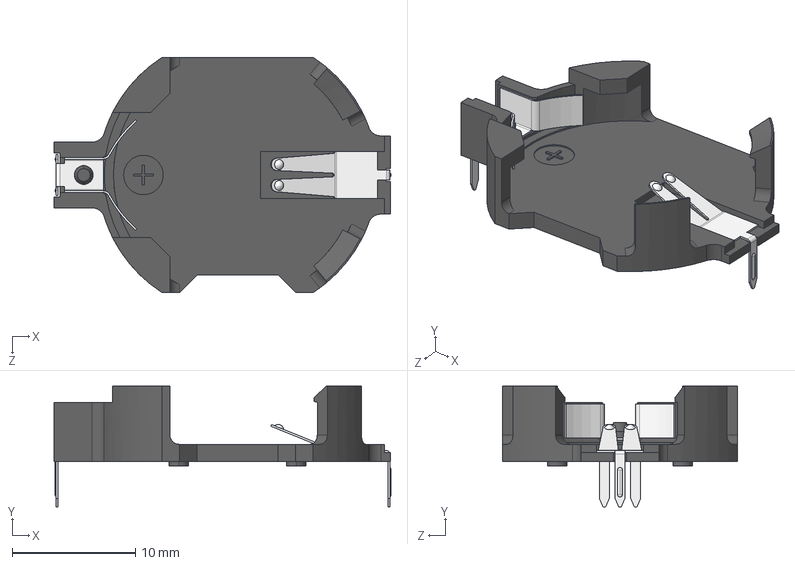
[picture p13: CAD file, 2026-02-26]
hardware/components/3D/120591-1.step
27.3 x 9.80 x 19.1 mm

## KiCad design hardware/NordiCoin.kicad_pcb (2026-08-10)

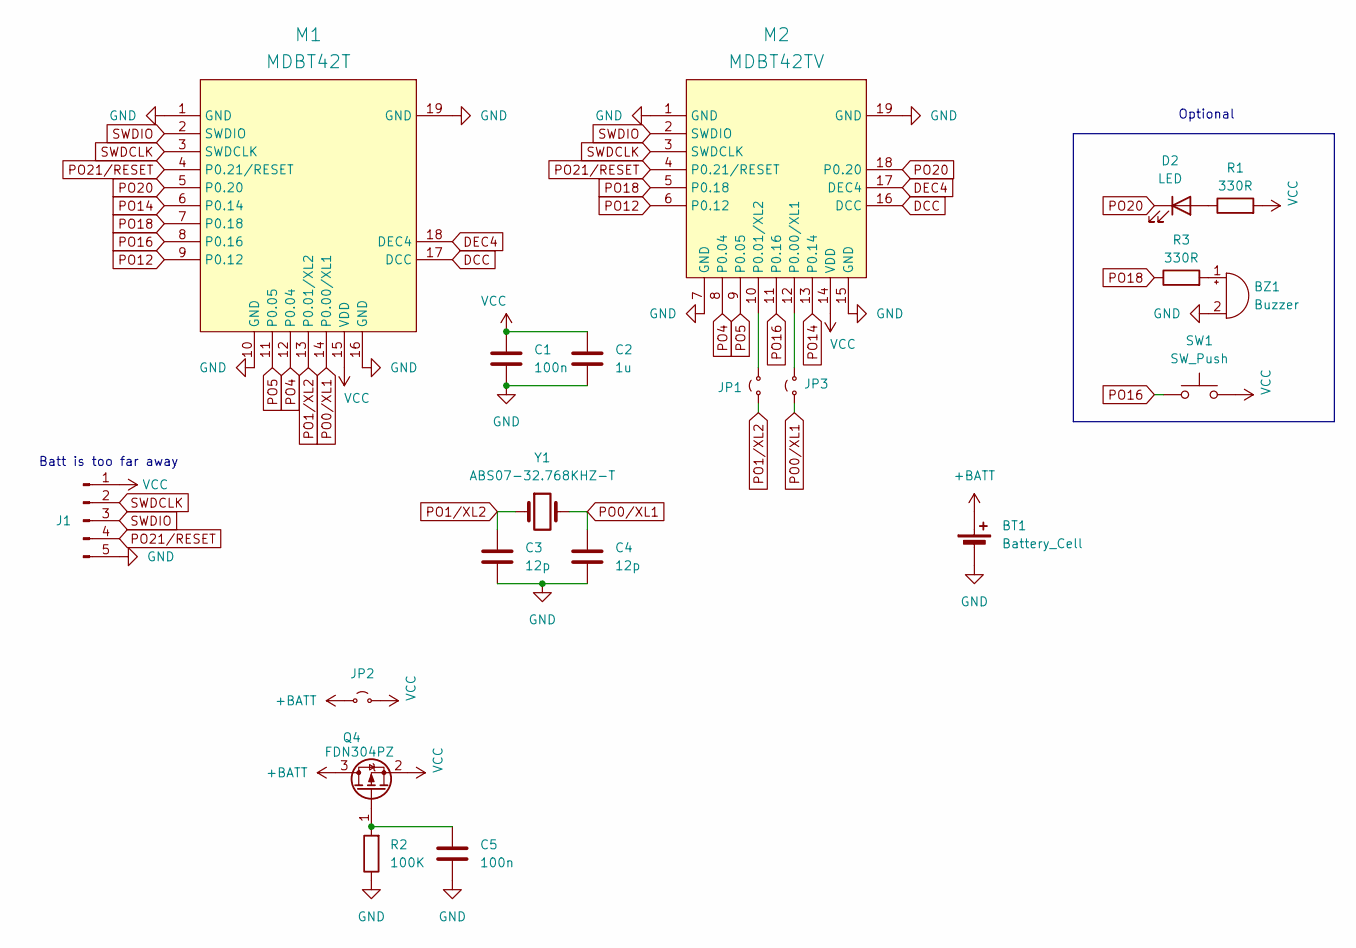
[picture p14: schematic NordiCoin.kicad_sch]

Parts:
BT1: Battery_Cell; BAT_120591-1
BZ1: Buzzer; AST0760_MAL
C1, C5: 100n; C_0603_1608Metric
C2: 1u; C_0603_1608Metric
C3, C4: 12p; C_0402_1005Metric
D2: LED; LED_0603_1608Metric
J1: Conn_01x05_Pin; PinHeader_1x05_P1.00mm_Vertical
JP1, JP2, JP3: Jumper_2_Small_Open; SolderJumper_UnBridged_Small
M1: MDBT42T
M2: MDBT42TV
Q4: FDN304PZ; SOT-23
R1, R3: 330R; C_0402_1005Metric
R2: 100K; C_0402_1005Metric
SW1: SW_Push; SW4_PTS815 SJM 250 SMTR LFS_CNK
Y1: ABS07-32.768KHZ-T; XTAL_9HT10_TXC

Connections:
+BATT: BT1.1 (+), JP2.1 (A), Q4.3 (D)
DCC: M1.17 (DCC), M2.16 (DCC)
DEC4: M1.18 (DEC4), M2.17 (DEC4)
GND: BT1.2 (-), BZ1.2 (-), C1.2, C2.2, C3.2, C4.2, C5.2, J1.5, M1.1 (GND), M1.10 (GND), M1.16 (GND), M1.19 (GND), M2.1 (GND), M2.7 (GND), M2.15 (GND), M2.19 (GND), R2.1
unnamed: BZ1.1 (+), R3.2
unnamed: D2.2 (A), R1.1
unnamed: JP1.2 (B), M2.10 (P0.01/XL2)
unnamed: JP3.2 (B), M2.12 (P0.00/XL1)
unnamed: C5.1, Q4.1 (G), R2.2
PO0/XL1: C4.1, JP3.1 (A), M1.14 (P0.00/XL1), Y1.2
PO1/XL2: C3.1, JP1.1 (A), M1.13 (P0.01/XL2), Y1.1
PO4: M1.12 (P0.04), M2.8 (P0.04)
PO5: M1.11 (P0.05), M2.9 (P0.05)
PO12: M1.9 (P0.12), M2.6 (P0.12)
PO14: M1.6 (P0.14), M2.13 (P0.14)
PO16: M1.8 (P0.16), M2.11 (P0.16), SW1.1
PO18: M1.7 (P0.18), M2.5 (P0.18), R3.1
PO20: D2.1 (K), M1.5 (P0.20), M2.18 (P0.20)
PO21/RESET: J1.4, M1.4 (P0.21/RESET), M2.4 (P0.21/RESET)
SWDCLK: J1.2, M1.3 (SWDCLK), M2.3 (SWDCLK)
SWDIO: J1.3, M1.2 (SWDIO), M2.2 (SWDIO)
VCC: C1.1, C2.1, J1.1, JP2.2 (B), M1.15 (VDD), M2.14 (VDD), Q4.2 (S), R1.2, SW1.2

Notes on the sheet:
Batt is too far away
Optional

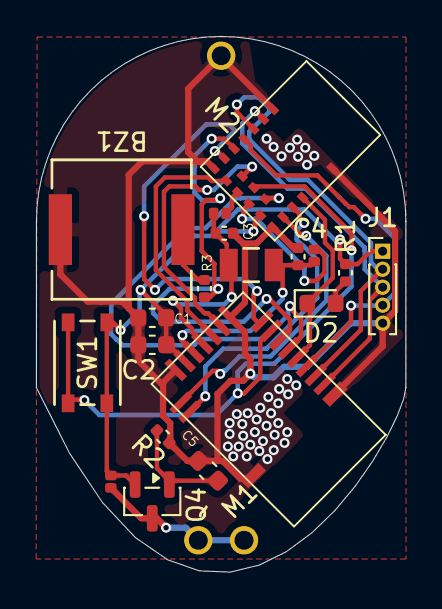
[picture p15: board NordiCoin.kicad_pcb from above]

Board: 2 copper layers, 20.5 x 29.8 mm, 20 parts (1 on the bottom side), 22 nets.

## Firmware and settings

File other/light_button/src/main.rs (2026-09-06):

#![no_std]
#![no_main]

mod ble;
mod config;
#[cfg(not(feature = "debug"))]
mod no_debug;
mod other;
mod peripherals;
mod prelude;

use embassy_executor::Spawner;
use nrf_mpsl::MultiprotocolServiceLayer;
use static_cell::StaticCell;

use prelude::*;

#[cfg(feature = "debug")]
use {defmt_rtt as _, panic_probe as _};

#[cfg(not(feature = "debug"))]
mod panic_handler;

bind_interrupts!(struct Irqs {
    RNG => rng::InterruptHandler<embassy_nrf::peripherals::RNG>;
    EGU0_SWI0 => nrf_sdc::mpsl::LowPrioInterruptHandler;
    CLOCK_POWER => nrf_sdc::mpsl::ClockInterruptHandler;
    RADIO => nrf_sdc::mpsl::HighPrioInterruptHandler;
    TIMER0 => nrf_sdc::mpsl::HighPrioInterruptHandler;
    RTC0 => nrf_sdc::mpsl::HighPrioInterruptHandler;
    SAADC => embassy_nrf::saadc::InterruptHandler;
});

#[embassy_executor::task]
async fn mpsl_task(mpsl: &'static MultiprotocolServiceLayer<'static>) -> ! {
    mpsl.run().await
}

#[embassy_executor::main]
async fn main(spawner: Spawner) {
    // ------------------------------------------------------------
    // nRF initialization
    // ------------------------------------------------------------

    let mut config = embassy_nrf::config::Config::default();
    config.lfclk_source = LfclkSource::ExternalXtal;

    let p = embassy_nrf::init(config);

    info!("Nordicoin start");

    // ------------------------------------------------------------
    // MPSL
    // ------------------------------------------------------------

    let mpsl_p =
        mpsl::Peripherals::new(p.RTC0, p.TIMER0, p.TEMP, p.PPI_CH19, p.PPI_CH30, p.PPI_CH31);

    let lfclk_cfg = mpsl::raw::mpsl_clock_lfclk_cfg_t {
        source: mpsl::raw::MPSL_CLOCK_LF_SRC_RC as u8,
        rc_ctiv: mpsl::raw::MPSL_RECOMMENDED_RC_CTIV as u8,
        rc_temp_ctiv: mpsl::raw::MPSL_RECOMMENDED_RC_TEMP_CTIV as u8,
        accuracy_ppm: mpsl::raw::MPSL_DEFAULT_CLOCK_ACCURACY_PPM as u16,
        skip_wait_lfclk_started: mpsl::raw::MPSL_DEFAULT_SKIP_WAIT_LFCLK_STARTED != 0,
    };

    static MPSL: StaticCell<MultiprotocolServiceLayer> = StaticCell::new();

    let mpsl = MPSL.init(MultiprotocolServiceLayer::new(mpsl_p, Irqs, lfclk_cfg).unwrap());

    spawner.spawn(mpsl_task(mpsl).unwrap());

    // ------------------------------------------------------------
    // SoftDevice Controller peripherals
    // ------------------------------------------------------------

    let sdc_p = sdc::Peripherals::new(
        p.PPI_CH17, p.PPI_CH18, p.PPI_CH20, p.PPI_CH21, p.PPI_CH22, p.PPI_CH23, p.PPI_CH24,
        p.PPI_CH25, p.PPI_CH26, p.PPI_CH27, p.PPI_CH28, p.PPI_CH29,
    );

    // ------------------------------------------------------------
    // RNG
    // ------------------------------------------------------------

    static RNG: StaticCell<rng::Rng<embassy_nrf::mode::Async>> = StaticCell::new();

    let rng = RNG.init(rng::Rng::new(p.RNG, Irqs));

    // ------------------------------------------------------------
    // SDC memory
    // ------------------------------------------------------------

    static SDC_MEM: StaticCell<sdc::Mem<6144>> = StaticCell::new();

    let sdc_mem = SDC_MEM.init(sdc::Mem::<6144>::new());

    // ------------------------------------------------------------
    // SoftDevice Controller
    // ------------------------------------------------------------

    let sdc = ble::build_sdc(sdc_p, rng, mpsl, sdc_mem).unwrap();

    // ------------------------------------------------------------
    // Start BLE task.
    //
    // HostResources, Stack, Runner and Central are all created
    // inside run_ble_task().
    // ------------------------------------------------------------
spawner.spawn(ble::run_ble_task(sdc).unwrap());
    spawner.spawn(
        peripherals_task(
            spawner,
            peripherals::led::LedController::new(20, p.P0_20),
            Input::new(p.P0_16, Pull::Down), // Needs a pull down! and without external resistor
        )
        .unwrap(),
    );

    LED_CHANNEL.send(LedCommand::Blink).await;
}

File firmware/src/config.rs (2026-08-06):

use crate::prelude::*;

// BLE
pub const SDC_MEM_SIZE: usize = 4696;
pub const BLE_NAME_NOT_BONDED: &'static str = "NordiCoin-";
pub const BLE_CONN_TIMEOUT_NOT_BONDED: Duration = Duration::from_secs(10);
pub const BLE_CONN_TIMEOUT_BONDED: Duration = Duration::from_secs(4);
pub const BLE_DEFAULT_TX_POWER: i8 = trouble_host::advertise::TxPower::ZerodBm as i8;
pub const BLE_REFRESH_BATTERY: Duration = Duration::from_secs(60 * 60 * 24); // 24h
pub const BLINK_ON_CONNECTION: bool = true; // Could be a feature to save a few bytes but nah
// Configuring these impacts battery life a lot, but also how easy it is to connect to it
// 5K is the limit, 3.9uA
// 4K is good, 4.3uA
pub const ADV_INTERVAL_MIN_MS: Duration = Duration::from_millis(4000);
pub const ADV_INTERVAL_MAX_MS: Duration = Duration::from_millis(4100);

// LED
pub const LED_BLINK_MS: Duration = Duration::from_millis(5);
pub const LED_BLINK_FOR_ON_MS: Duration = Duration::from_millis(50);
pub const LED_BLINK_FOR_OFF_MS: Duration = Duration::from_millis(500);

// PWM
pub const PWM_BASE_FREQ: u32 = 6000;
pub const PWM_FREQ_TOLERANCE: u16 = 400;
pub const PWM_FREQ_STEP: u16 = 200;
pub const PWM_BASE_DUTY: u8 = 50;
pub const PWM_BASE_DELAY_MS: Duration = Duration::from_millis(90);

// Button
pub const BUTTON_HOLD_TIME: Duration = Duration::from_secs(5);

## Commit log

2026-02-25 added mcus
    [NordiCoin.kicad_sch]
2026-02-26 Layout done
    [120591-1.step, CR2032.step, MDBT42T.stp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]
2026-02-26 keep out tracks
    [NordiCoin.kicad_pcb]
2026-02-26 done maybe
    [NordiCoin.kicad_pcb]
2026-07-07 update kicad version
    [NordiCoin.kicad_pcb, NordiCoin.kicad_sch]
2026-07-07 firmware running not working
    [120591-1.step, CR2032.step, MDBT42T.stp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]
2026-07-10 adc works
2026-07-10 adc better
2026-07-10 final tests
    [battery_life.ods]
2026-07-11 finds but doesn't connect
    [main.rs]
2026-07-11 pwm works but no sound
2026-07-11 pwm almost working, sometimes getting stuck and not outputting anything
    [main.rs]
2026-07-12 pwm finish
2026-07-12 LED done
2026-07-15 button working
2026-07-15 For some reason this causes bluetooth to fail on readvertising, probably because it's missing memory?
    [advertise.rs, main.rs, mod.rs]
2026-07-16 button, final fixes
2026-07-18 pwm test now consuming less power
2026-07-18 fixed pwm
2026-07-18 pwm working i promise
2026-07-24 adding device
2026-07-25 show added devices prototype
2026-07-26 kicad 3D files, scanning, refreshing, battery reading
    [ABS07-32.768KHZ-T--3DModel-STEP-400430.STEP, AST0760_MAL.step, NordiCoin.kicad_pcb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]
2026-08-05 Scan duration, alerts per device optimisations
2026-08-10 some pcb adjustments
    [NordiCoin.kicad_pcb, NordiCoin.kicad_sch]
2026-08-10 batt life
    [battery_life.ods]
2026-08-14 show error in status scan, cancel notification if device found in background scan
